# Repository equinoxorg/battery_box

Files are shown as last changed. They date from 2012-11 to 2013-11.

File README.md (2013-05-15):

#Battery Box 2013 Prototype

##Hardware
Hardware designs are made in eagle v6

##Software
Software is MPLAB IDE X v1.30 with the Hi Tech C Lite compiler

##Changes from 2012
Added Current Sense to prevent overcurrent failure
* Changed Microcontroller to add no volatile memory
  * Can be used to prevent over discharge and better batt level estimation
  * Can be used as very simple datalogger, data can be exported through Serial Data out pins
* Connectors have been added to board to reduce assembely time
* Surface mount components used to reduce manufacture cost

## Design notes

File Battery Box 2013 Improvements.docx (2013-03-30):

# Battery Box 2013 Improvements

# Surface Mount

All components should be replaced with their surface mount equivalent. For the resistors and capacitors the size of the devices should be 0805 to make hand soldering of test boards possible.

Some components will not be able to be switched to surface mount be switching as many as possible will bring down production costs and they will be able to be machine soldered.

# USB Changes

Firstly the USB power should have current limiting on. This will prevent damage to phones which try to pull more than 500mA. It will also stop the audible ringing when this situation occurs. To implement this we can use a device such as this (http://onecall.farnell.com/diodes-inc/ap1212lsg-13/ic-switch-usb-low-8sop/dp/1825303).

Secondly a voltage bias should be added to the USB data lines, this will make our charging ports compatible with more devices. The following website have looked into the correct biasing in detail and found these values to be the most compatible.

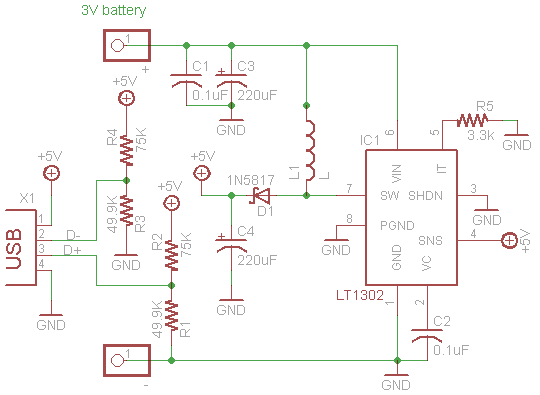
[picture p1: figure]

Figure 1- http://www.ladyada.net/make/mintyboost/parts.html

# Connector Mountings

Rather than connecting the mounting through terminal blocks and wires we should be mounting them straight onto the PCB and mounting the PCB directly behind the faceplate. For this we will carry on using the vertical mount USB sockets (here (http://onecall.farnell.com/lumberg/2410-01/usb-type-a-receptacle-panel/dp/1177882?Ntt=117-7882)) but will have to switch from panel mount to vertical PCB mount DC jacks. These jacks look suitable (http://uk.mouser.com/ProductDetail/Kycon/KLDVX-0202-B/?qs=sGAEpiMZZMvEZpvz4iUm3q0Yvn/b8os7).

We will also need to investigate how to mount the PCBs securely to the faceplate. The only connect made off the PCB will be to the power switch and battery. However if we could also mount the power switch on the PCB also then this would be beneficial but this seems very difficult. The battery and switch should be connected using something like this (http://onecall.farnell.com/molex/26-03-4020/housing-3-96mm-2way/dp/1756831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) which should be easier, more reliable and cheaper than the terminal blocks.

# Protection Circuit

Currently we have a PTC and fuse. These do not protect the Mosfet during over-current (output shorted to ground) situations as they do not act fast enough. Many boxes are failing due to this. We need to add faster acting input protection, possible a current sense resistor with the voltage drop connected to the analogue comparator of the PIC, this can be linked to an interrupt to disable the output and indicate the user of the error. This may still not be fast enough, so could also add a more resilient Mosfet.

Reverse battery protection could also be added if this is found to cause damage to the electrosnic.

# Charging Indication

We should provide some visual indication id charging. This can simply be done by flashing the bi-colour LED during charging.

# Optional Data-logging Unit

We would like a way to optional add data-logging systems to these boxes. This would profile how they are being used over time. We would not add these to all boxes due to cost but it would be nice to have the option to add this to some boxes. We could either design all PCBs to be able to do this but only solder the required data-logging components to selected boxes or add in a second data-logging PCB which monitors usage. We would have to think carefully about how we would retrieve the data from these boxes.

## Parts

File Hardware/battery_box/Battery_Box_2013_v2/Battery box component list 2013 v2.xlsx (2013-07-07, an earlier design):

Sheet: Component Sheet
 |  | Battery Box component list 2013
Board label | Quantity | Function | Manufacturer | Order code | Quantity | Price | Total Cost | Comments | Current quantity
 | 2 | Crimp terminal for plug | MOLEX | 2063715 | 2 | £0.14 | £0.28
 | 1 | Receptacle connector | MOLEX | 151866 | 1 | £0.17 | £0.17
 | 1 | Battery Crimp red | Multicomp | 9971882 | 1 | £0.16 | £0.16 | could get cheaper 1339227, but test quality first
 | 1 | Battery Crimp blue | MULTICOMP | 9971904 | 1 | £0.14 | £0.14 | Could get cheaper 488331, but test quality first
 | 1 | LED Housing | KINGBRIGHT | 1105124 | 1 | £0.10 | £0.10
 |  | Cable
 |  | PCB
 |  | USBS |  | 1696536 | 1 | £0.26 | £0.26 |  | 200
 |  | Programmer header | TE CONNECTIVITY / AMP | 1248143 |  |  |  | NOT ACTUALLY NEEDED TE CONNECTIVITY / AMP - 826926-5 - HEADER, STRAIGHT, 5WAY | 180
 | 1 | LED |  | 2001770 | 1 | £0.14 | £0.14 |  | 200
 | 2 | DC Socket |  |  | 2 | £0.22 | £0.44 | price for 500+ | 200
 | 1 | Battery connector header | MOLEX | 1012166 | 1 | £0.41 | £0.41 |  | 200
SW_POW | 1 | Switch | TE CONNECTIVITY | 758-1979 | 1 | £0.08 | £0.08 |  | 200
 | 1 | Switch Cap | MULTICOMP | 9561552 | 1 | £0.03 | £0.03 | MULTICOMP - KTSC-22K - CAP, ROUND, BLACK | 200
PTC | 1 | PTC | TE CONNECTIVITY | 1345935 | 1 | £0.19 | £0.19 |  | 3
IC4 | 1 | 5V regulator | NXP | 2057286 | 1 | £0.02 | £0.02 |  | 200
IC3 | 1 | PIC microcontroller | MICROCHIP | 1814945 | 1 | £1.01 | £1.01 | 70p in bulk | 192
R9, R16, R17 | 3 | 20k resistor | MULTICOMP | 2074395 | 3 | £0.01 | £0.03 |  | 92
R10, R19 | 2 | 10k resistor | MULTICOMP | 2074334 | 2 | £0.01 | £0.02
R12, R13 | 2 | 100k Resistor | MULTICOMP | 2073608 | 2 | £0.01 | £0.02 |  | 95
R1, R3 | 2 | 75k Resistor | MULTICOMP | 2073840 | 2 | £0.01 | £0.02 |  | 95
R14, R15 | 2 | 66k5 Resistor | VISHAY | 2139016 | 2 | £0.01 | £0.01 |  | 45
R2, R4 | 2 | 49.9k Resistor | PANASONIC | 2057651 | 2 | £0.02 | £0.03 |  | 45
R5, R6, R7 | 3 | 1k Resistor | MULTICOMP | 2073611 | 3 | £0.01 | £0.02 |  | 85
R18 | 1 | 1M Resistor | MULTICOMP | 2073615 | 1 | £0.01 | £0.01 |  | 98
R11 | 1 | 0.1 ohm resistor | BOURNS | 1865265 | 1 | £0.12 | £0.18 |  | 209
C1 | 1 | 1u capacitor | MULTICOMP | CA06731 | 1 | £0.01 | £0.01 |  | 99
C4 | 1 | 22u capacitor, 6.3v | MULTICOMP | CA06719 | 1 | £0.08 | £0.08 |  | 90
C2 | 1 | 22u capacitor, 16V | MULTICOMP | CA06789 | 1 | £0.23 | £0.23 |  | 200
C3 | 1 | 220u capacitor, 6.3V | PANASONIC | 9694340 | 1 | £0.35 | £0.35
IC2 | 1 | 12-5V Regulator | TEXAS INSTRUMENTS | SC10367 | 1 | £0.63 | £0.63 |  | 193
L1 | 1 | Inductor | MULTICOMP | 1864293 | 1 | £0.28 | £0.28 |  | 193
Q1 | 1 | P-MOS Power MOSFET | International Rectifier | 8649839 | 1 | £0.32 | £0.32 |  | 203
Q2 | 1 | N-MOS Signal MOSFET | NXP | 2191748 | 1 | £0.03 | £0.03 |  | 202
IC1 | 1 | Operational Amplifier | TEXAS INSTRUMENTS | 1755223 | 1 | £0.25 | £0.25 |  | 203
C5 | 1 | 10u Capacitor | MULTICOMP | 1759470 | 1 | 0.26 | 0.26 |  |  | 5
D2, D3 | 2 | Schottky Diode 40V output | MULTICOMP | 1861427 | 2 | 0.121 | 0.242 | Could be cheaper? | 400 | 5
D1 | 1 | Schottky Diode 20V output | MULTICOMP | 1861424 | 1 | 0.05 | 0.05 |  | 200 | 5
C6 | 1 | 0.1u Capacitor | AVX | 1327657 | 1 | 0.033 | 0.033 | Could get cheaper in smaller package, but didn’t have time to redesign board |  | 5
C8 | 1 | 10u Capacitor | TDK | 2309029 | 1 | 0.028 | 0.028 |  |  | 5
 |  |  |  |  |  |  | £6.55

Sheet: Ordering Sheet
 | Supplier Ref | Quantity | Description | Our Description
 | 1248143 | 200 | TE CONNECTIVITY / AMP - 826926-5 - HEADER, STRAIGHT, 5WAY | programmer thing!!! (headers)
 | 2073608 | 400 | MULTICOMP - MCMR08X1003FTL - RESISTOR, CERAMIC, 100K, 0.125W, 1% | 100k Resistor | x
 | 1012166 | 200 | MOLEX - 39-29-1028 - HEADER, RIGHT ANGLE, MINI-FIT, 2WAY | Battery connector header
Check this | 1555983 | 200 | TE CONNECTIVITY / ALCOSWITCH - FSM6JH - SWITCH, SPST, 0.05A, 24VDC, THT | Switch
 | 1345935 | 200 | TE CONNECTIVITY / RAYCHEM - MINISMDC260F - POLYSWITCH, SMD, 1812, 2.6A | PTC
 | 2057286 | 200 | NXP - NX1117CE50Z - LDO, 5.0V, 1.25%, SOT223 | 5V regulator
 | 1814945 | 200 | MICROCHIP - PIC16F1824-I/SL - MCU, 8BIT, 7K FLASH, 12 I/O, 14SOIC | PIC microcontroller
 | 2074395 | 600 | MULTICOMP - MCSR08X2002FTL - RESISTOR, 0805, 20K, 1%, ANTI SULFUR | 20k resistor | x
 | 2074334 | 400 | MULTICOMP - MCSR08X1002FTL - RESISTOR, CERAMIC, 10K, 0.125W, 1% | 10k resistor | x
 | 2073840 | 400 | MULTICOMP - MCMR08X7502FTL - RESISTOR, 0805, 75K, 1%, ANTI SULFUR | 75k Resistor | x
 | 2139016 | 400 | VISHAY DRALORIC - CRCW080566K5FKEA - RESISTOR, 0805, 66K5, 1% | 66k5 Resistor
 | 2057651 | 400 | PANASONIC - ERJ6ENF4992V - RESISTOR, 0805, 49K9 1%, 0.125W | 49.9k Resistor
 | 2073611 | 600 | MULTICOMP - MCMR08X102 JTL - RESISTOR, ANTI SULFUR, 1K, 0805, 5% | 1k Resistor | X
 | 2073615 | 200 | MULTICOMP - MCMR08X105 JTL - RESISTOR, ANTI SULFUR, 1M, 0805, 5% | 1M Resistor | X
 | 1865265 | 200 | BOURNS - CRM2512-FX-R100ELF - RESISTOR, 0.100R, 2W, 1% | 0.1 ohm resistor
 | CA06731 | 200 | MULTICOMP - MCCA000543 - MLCC, 0805, Y5V, 16V, 1UF | 1u capacitor
Check this | CA06719 | 200 | MULTICOMP - MCCA000536 - MLCC, 0805, X5R, 6.3V, 22UF | 22u capacitor, 6.3v
Check this | CA06789 | 200 | MULTICOMP - MCCA000583 - MLCC, 1210, X5R, 16V, 22UF | 22u capacitor, 16V
 | 9694340 | 200 | PANASONIC - EEEFC0J221P - CAP ALUM ELEC, 220UF, 6.3V, 20%, SMD | 220u capacitor, 6.3V
 | SC10367 | 200 | TEXAS INSTRUMENTS - LM2574M-5.0 - SWITCHING REG 0.5A 5.0V, SMD, 2574 | 12-5V Regulator
 | 1864293 | 200 | MULTICOMP - MCBFS7330-331MU - INDUCTOR, 330UH, 20%, 1.15A | Inductor
 | 8649839 | 200 | INTERNATIONAL RECTIFIER - IRFR5505PBF - MOSFET, P, -55V, -18A, D-PAK | P-MOS Power MOSFET
 | 2191748 | 200 | NXP - NX7002AKW - MOSFET, SINGLE, N-CH, 60V, 0.17A, SOT323 | N-MOS Signal MOSFET
 | 1755223 | 200 | TEXAS INSTRUMENTS - TL103WID - IC, OP-AMP GP 900KHZ DUAL 8SOIC | Operational Amplifier
 | 1759470 | 200 | MULTICOMP - MCCA000586 - MLCC, 1210, X5R, 25V, 10UF | 10u Capacitor
 | 1861427 | 400 | MULTICOMP - SS54 - DIODE, SCHOTTK, RECTIF, 5A, 40V, SMC | Schottky Diode 40V output
 | 1861424 | 200 | MULTICOMP - SS12B - DIODE, SCHOTTK, RECTIF, 1A, 20V, SMB | Schottky Diode 20V output
 | 1327657 | 200 | AVX - 04026D104KAT2A - CAP MLCC, 0.1UF, 6.3V, X5R, 10%, 0402 | 0.1u Capacitor | x
 | 2309029 | 200 | TDK - C2012X5R0J106M/1.25 - CAPACITOR , 10UF, 6.3V, X5R, 20%, 0805 | 10u Capacitor

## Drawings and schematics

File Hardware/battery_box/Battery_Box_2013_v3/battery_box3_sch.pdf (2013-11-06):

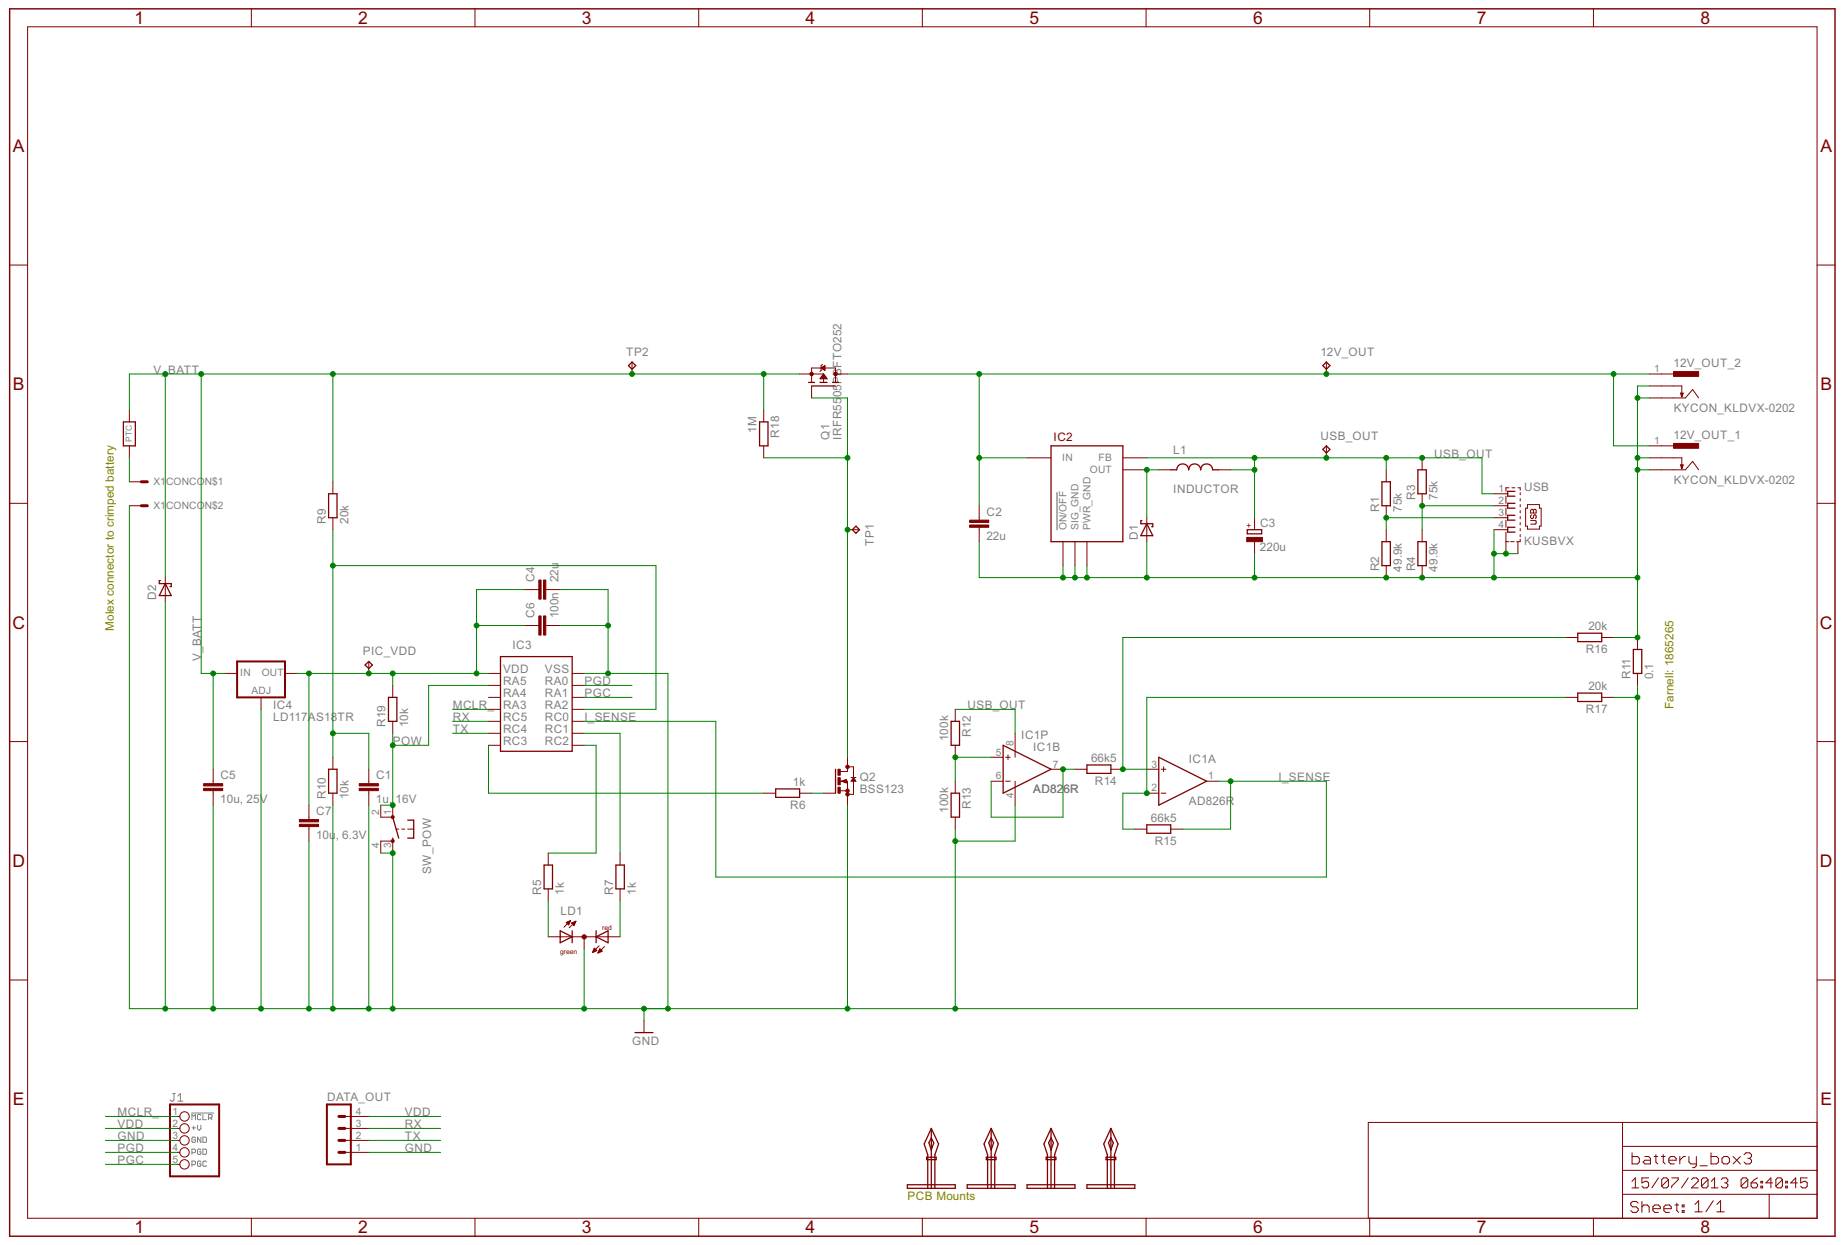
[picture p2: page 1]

Molex connector to crimped battery

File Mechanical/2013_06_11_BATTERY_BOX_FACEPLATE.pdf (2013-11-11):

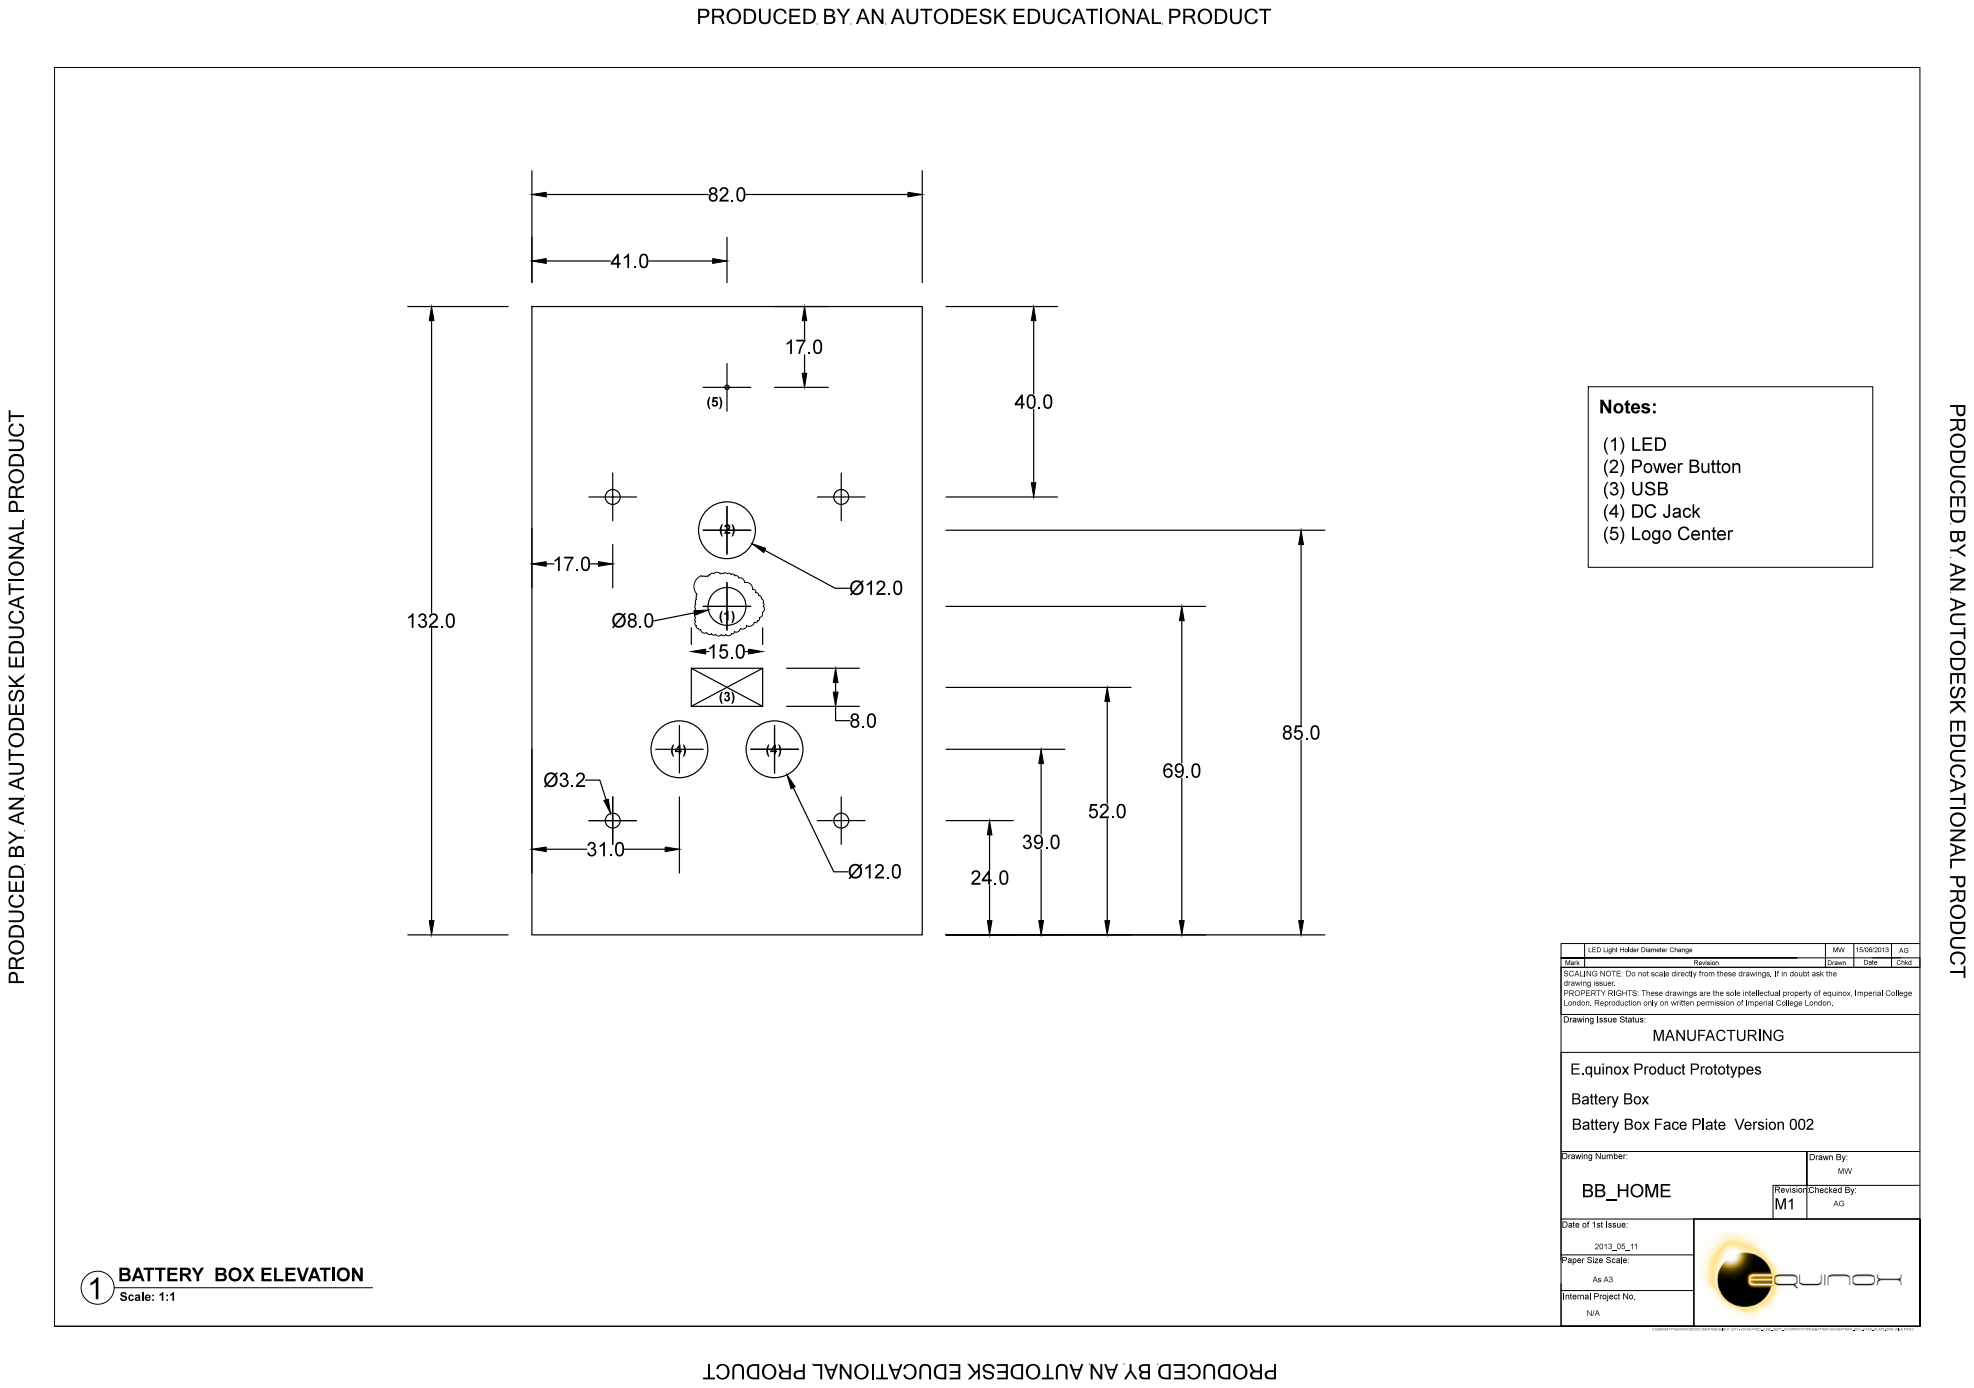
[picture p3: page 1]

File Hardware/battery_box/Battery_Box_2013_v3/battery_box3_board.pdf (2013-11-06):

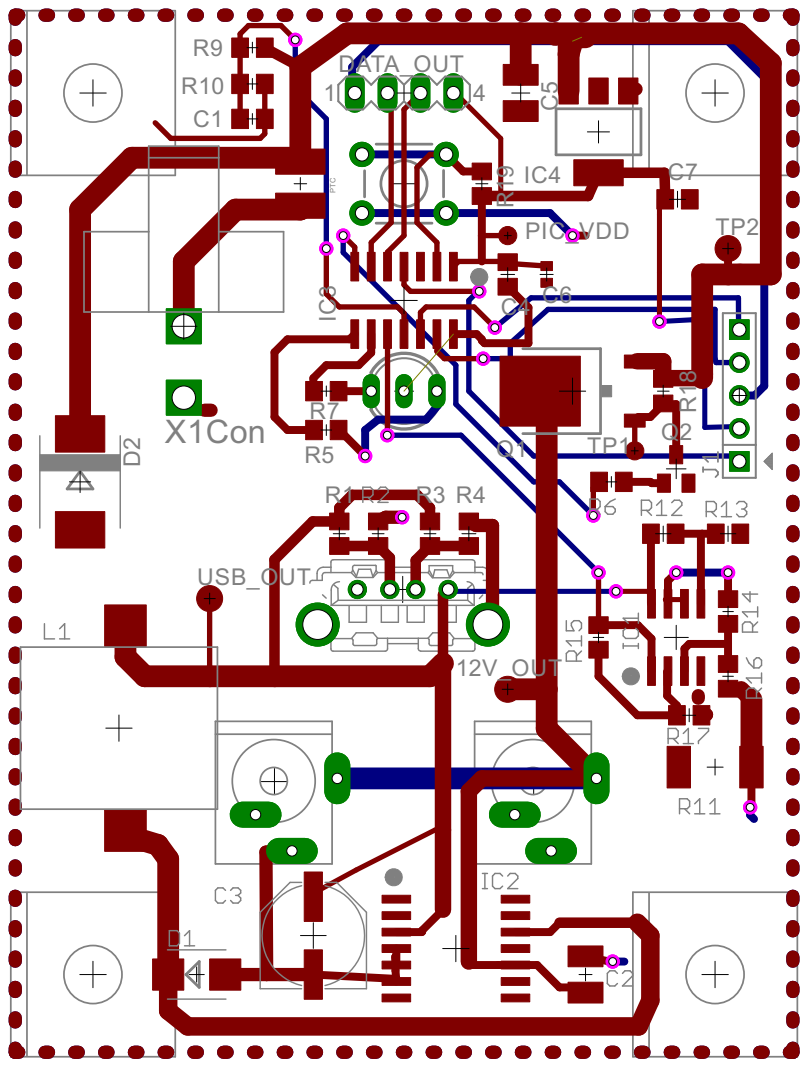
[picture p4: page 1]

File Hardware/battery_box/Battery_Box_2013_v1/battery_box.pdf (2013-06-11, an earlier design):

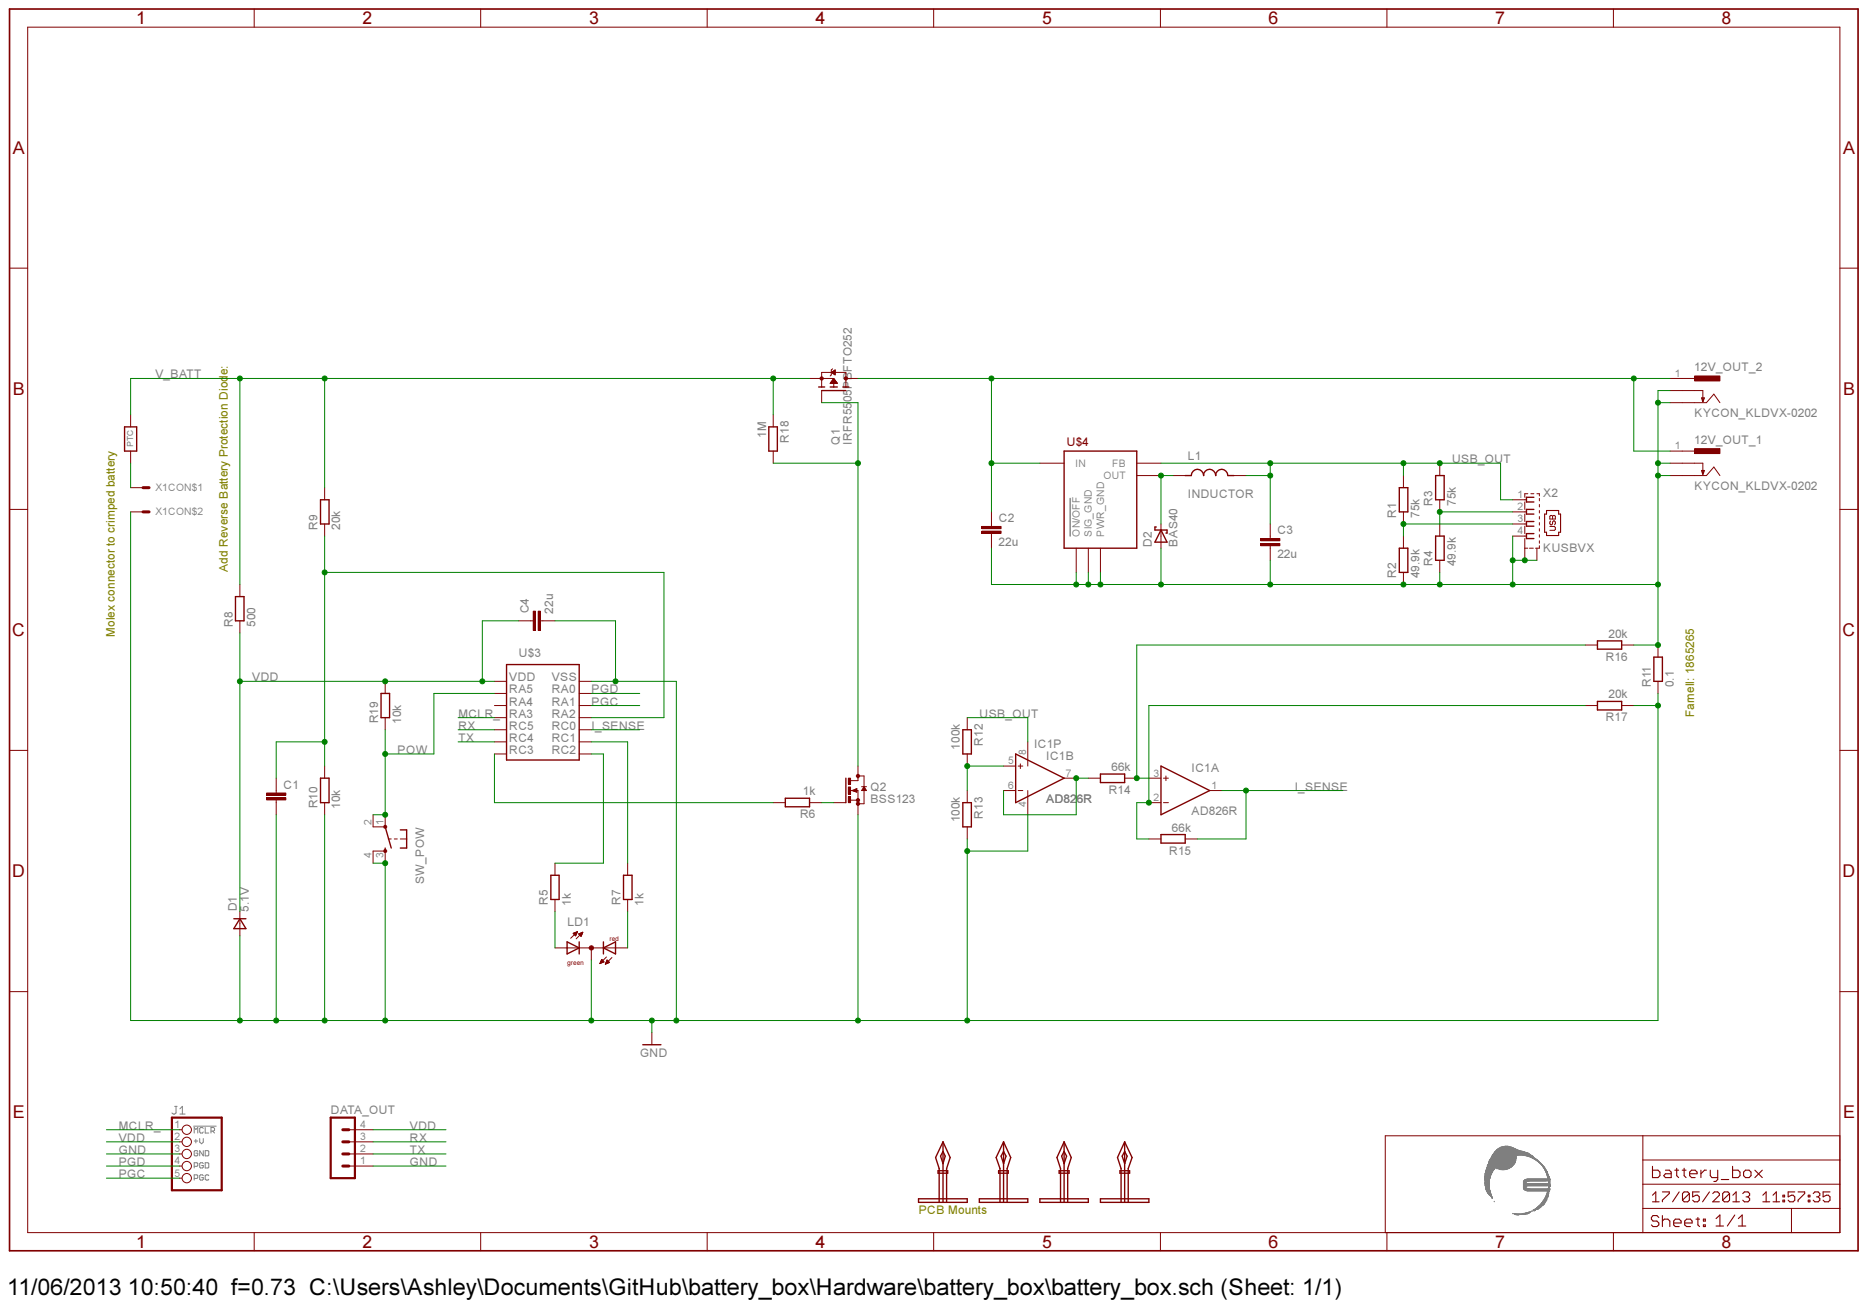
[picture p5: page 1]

Add Reverse Battery Protection Diode:

Molex connector to crimped battery

11/06/2013 10:50:40 f=0.73 C:\Users\Ashley\Documents\GitHub\battery_box\Hardware\battery_box\battery_box.sch (Sheet: 1/1)

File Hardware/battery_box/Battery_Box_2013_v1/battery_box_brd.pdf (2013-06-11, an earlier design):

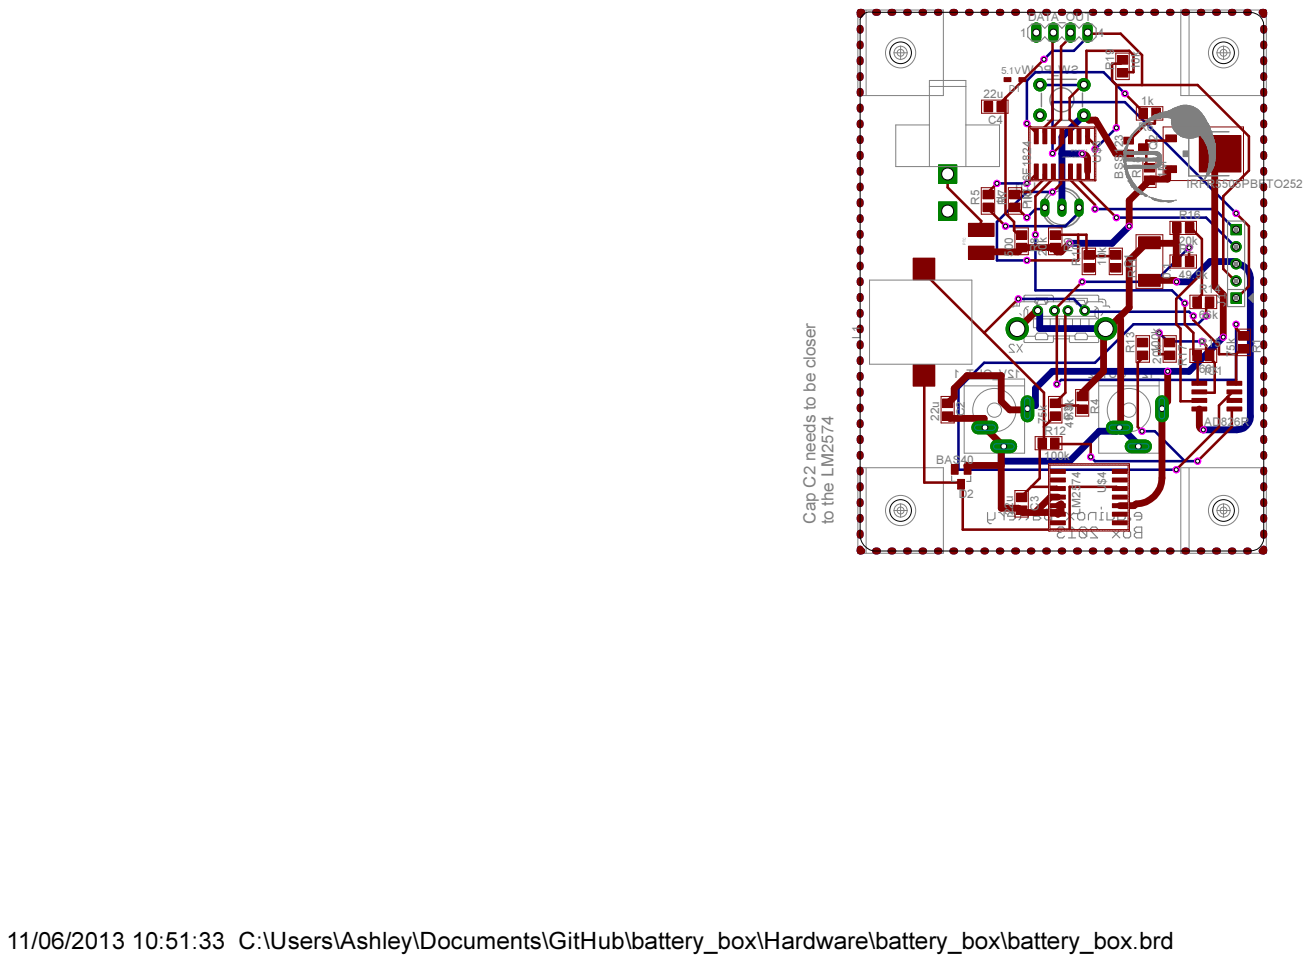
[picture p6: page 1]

Cap C2 needs to be closer

11/06/2013 10:51:33 C:\Users\Ashley\Documents\GitHub\battery_box\Hardware\battery_box\battery_box.brd

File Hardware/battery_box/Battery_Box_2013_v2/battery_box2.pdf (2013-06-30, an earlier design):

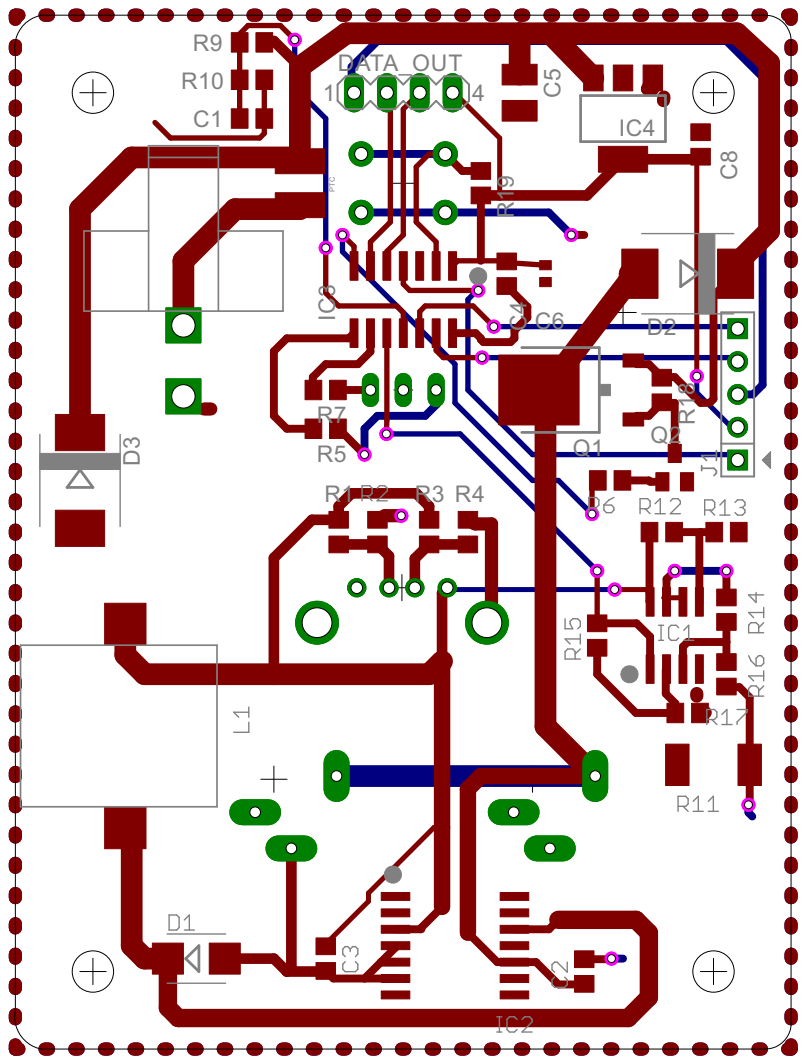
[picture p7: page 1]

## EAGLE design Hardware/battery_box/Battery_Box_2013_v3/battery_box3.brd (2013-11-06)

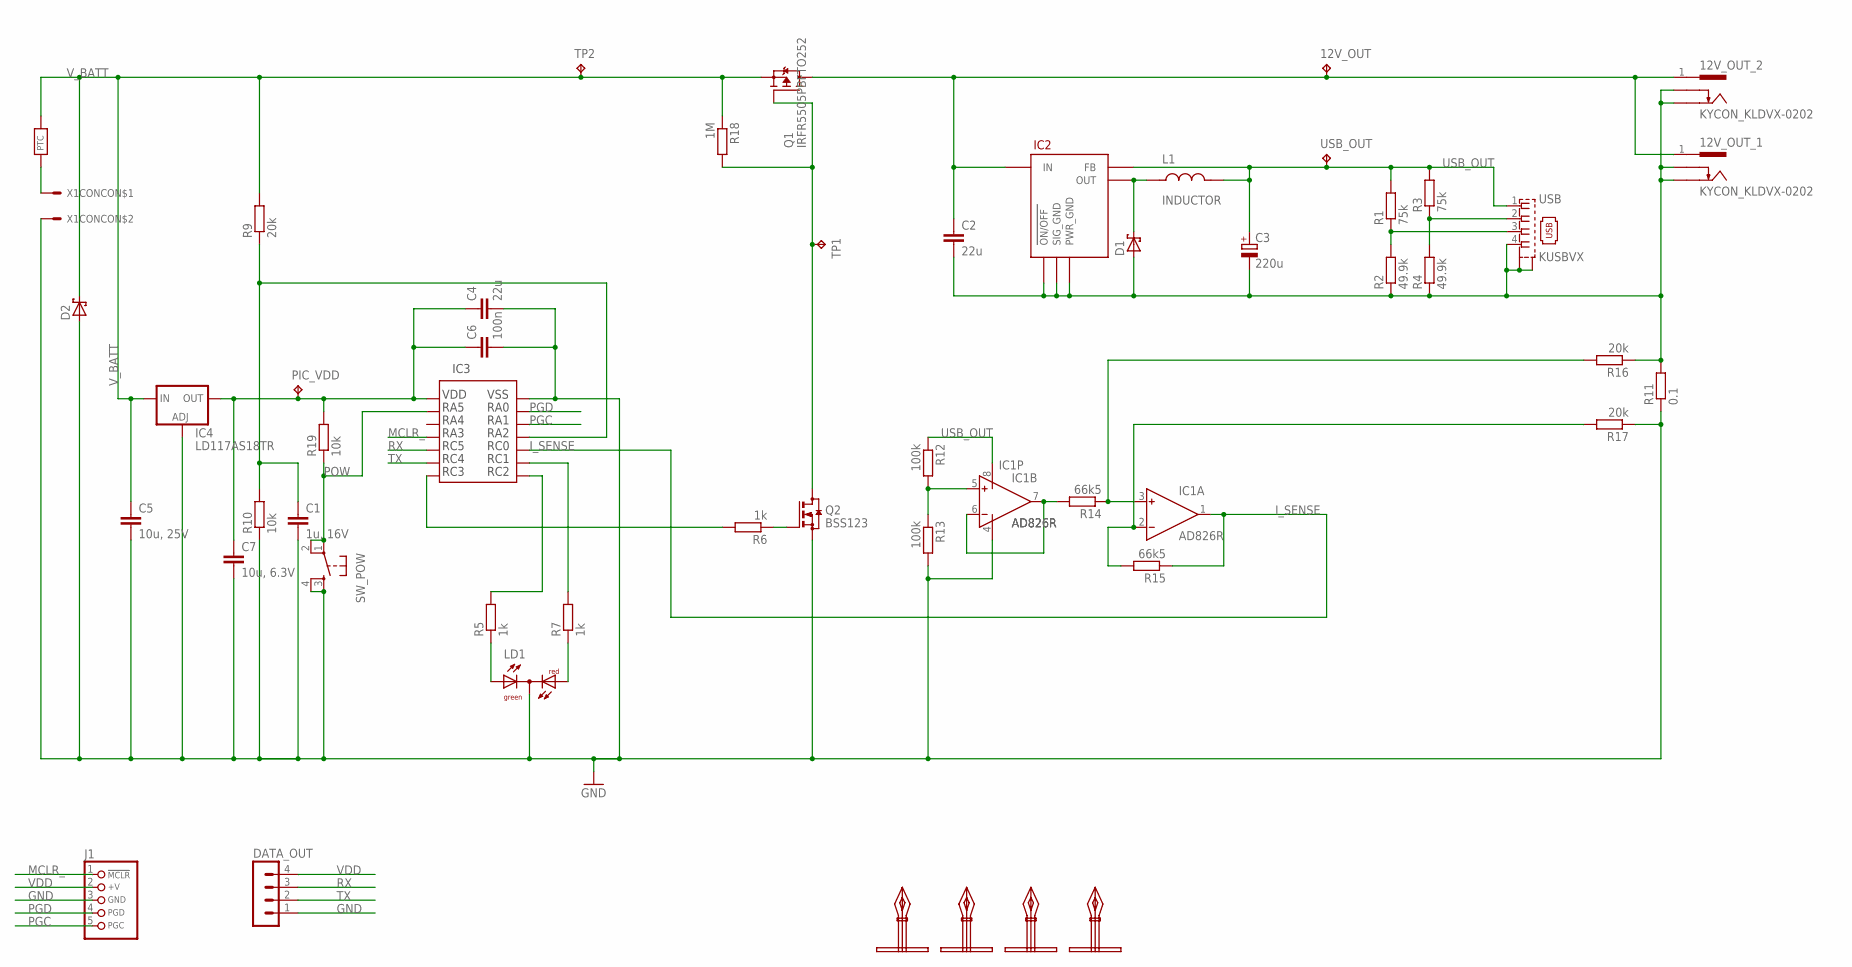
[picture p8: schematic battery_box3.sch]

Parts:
12V_OUT: TPTP20R; TP20R
12V_OUT_1, 12V_OUT_2: KYCON_KLDVX-0202; KYCON_KLVDX_2020_B
C1: 1u, 16V; C0805
C2: 22u; C1210
C3: 220u; PANASONIC_E
C4: 22u; C0805
C5: 10u, 25V; C1210
C6: 100n; C0402
C7: 10u, 6.3V; C0805
D1: SCHOTTKY-DIODESMD; SMB
D2: SCHOTTKY-DIODESMC; SMC
DATA_OUT: MA04-1
IC1: AD826R; SO8
IC2: LM2574; SO14W
IC3: PIC16F1824; SO-14
IC4: LD117AS18TR; SOT223
J1: CON_HEADER_PRG_PIC_ICSPA; HEADER_PRG_1X05
L1: INDUCTOR; SMD_INDUCTOR
LD1: DUOLED-RG-C; DUOLED-C-5MM
PIC_VDD: TPTP14R; TP14R
Q1: IRFR5505PBFTO252; TO252
Q2: BSS123; SOT23
R1, R3: 75k; R0805
R2, R4: 49.9k; R0805
R5, R6, R7: 1k; R0805
R9, R16, R17: 20k; R0805
R10, R19: 10k; R0805
R11: 0.1; R2512
R12, R13: 100k; R0805
R14, R15: 66k5; R0805
R18: 1M; R0805
SW_POW: TAC_SWITCHPTH; TACTILE-PTH
TP1: TPTP14R; TP14R
TP2: TPTP20R; TP20R
U$2: PTC; MINISMDC260F
U$5, U$6, U$7, U$8: PCB_MOUNT_RICHO; PCBMOUNT
USB: KUSBVX
USB_OUT: TPTP20R; TP20R
X1CON: CON_MOLEX_39_29_1028; MOLEX_39_29_1028

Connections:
12V_OUT: 12V_OUT.TP, 12V_OUT_1.1, 12V_OUT_2.1, C2.1, IC2.10 (IN), Q1.3 (D)
GND: C1.2, C4.2, C5.2, C6.2, C7.2, D2.A, DATA_OUT.1, IC1.4 (V-), IC3.14, IC4.1 (ADJ), J1.3 (GND), LD1.C, Q2.2 (S), R10.1, R11.1, R13.2, R17.1, SW_POW.3, SW_POW.4, X1CON.P$2
GND_OUTPUT: 12V_OUT_1.2, 12V_OUT_1.3, 12V_OUT_2.2, 12V_OUT_2.3, C2.2, C3.-, D1.A, IC2.4 (SIG_GND), IC2.5 (ON/OFF), IC2.6 (PWR_GND), R2.1, R4.1, R11.2, R16.1, USB.4, USB.M1 (S1), USB.M2 (S2)
I_SENSE: IC1.1 (OUT), IC3.10, R15.1
MCLR_: IC3.4, J1.1 (/MCLR)
unnamed: LD1.AR, R7.1
unnamed: R1.1, R2.2, USB.3
unnamed: LD1.AX (AG), R5.1
unnamed: R3.1, R4.2, USB.2
unnamed: U$2.P$1, X1CON.P$1
unnamed: IC3.9, R7.2
unnamed: C1.1, IC3.11, R9.1, R10.2
unnamed: D1.C, IC2.12 (OUT), L1.P$1
unnamed: IC3.8, R5.2
unnamed: Q1.1 (G), Q2.3 (D), R18.2, TP1.TP
unnamed: Q2.1 (G), R6.1
unnamed: IC3.7, R6.2
unnamed: IC1.3 (IN+), R14.1, R16.2
unnamed: IC1.2 (IN-), R15.2, R17.2
unnamed: IC1.5 (IN+), R12.2, R13.1
unnamed: IC1.6 (IN-), IC1.7 (OUT), R14.2
PGC: IC3.12, J1.5 (PGC)
PGD: IC3.13, J1.4 (PGD)
POW: IC3.2, R19.1, SW_POW.1, SW_POW.2
RX: DATA_OUT.3, IC3.5
TX: DATA_OUT.2, IC3.6
USB_OUT: C3.+, IC1.8 (V+), IC2.3 (FB), L1.P$2, R1.2, R3.2, R12.1, USB.1, USB_OUT.TP
VDD: C4.1, C6.1, C7.1, DATA_OUT.4, IC3.1, IC4.4 (OUT), J1.2 (+V), PIC_VDD.TP, R19.2
V_BATT: C5.1, D2.C, IC4.3 (IN), Q1.2 (S), R9.2, R18.1, TP2.TP, U$2.P$2

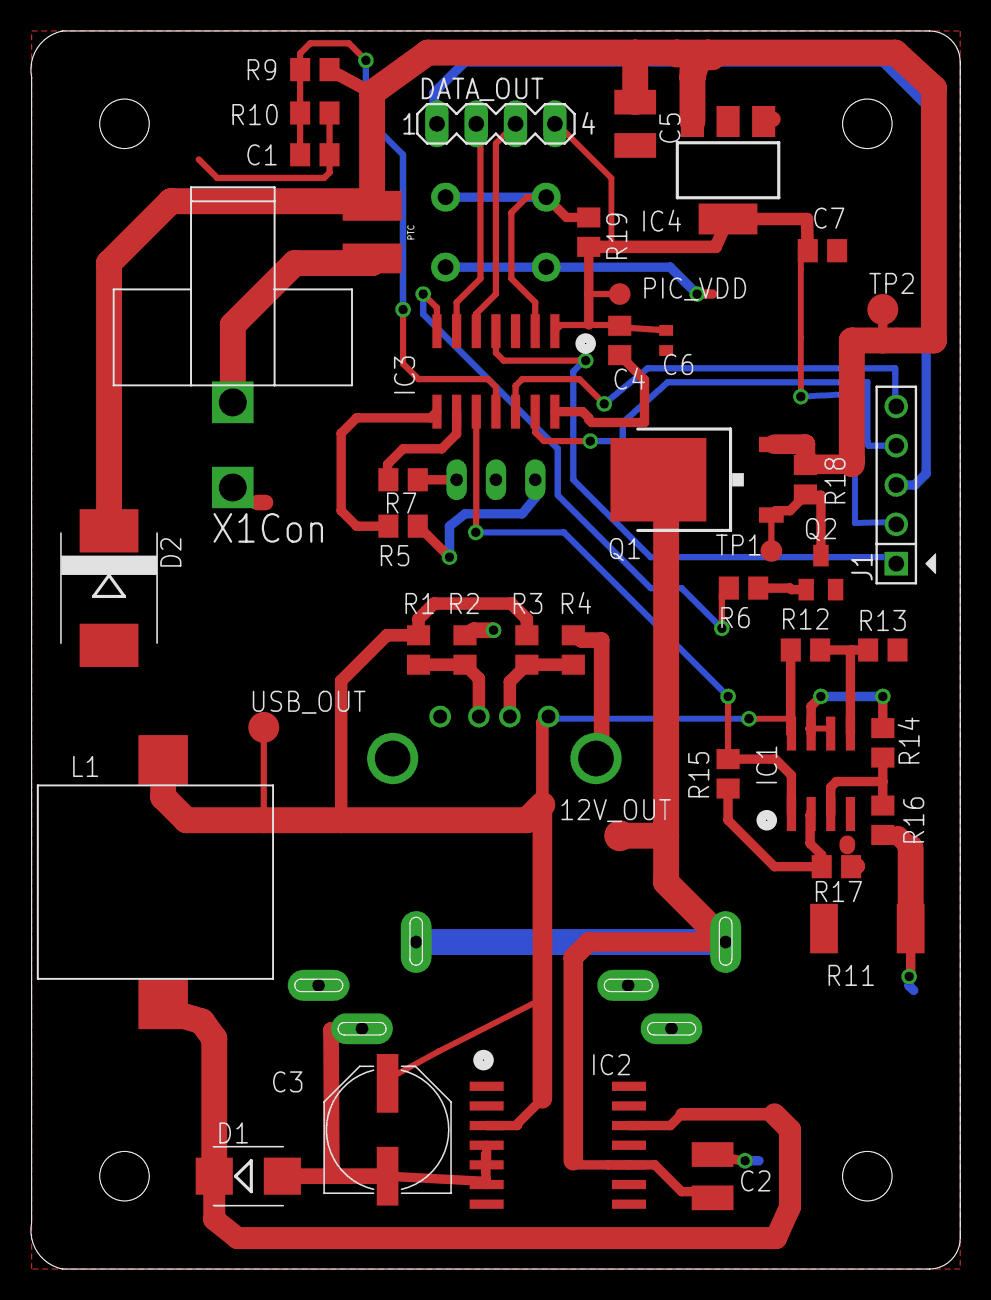
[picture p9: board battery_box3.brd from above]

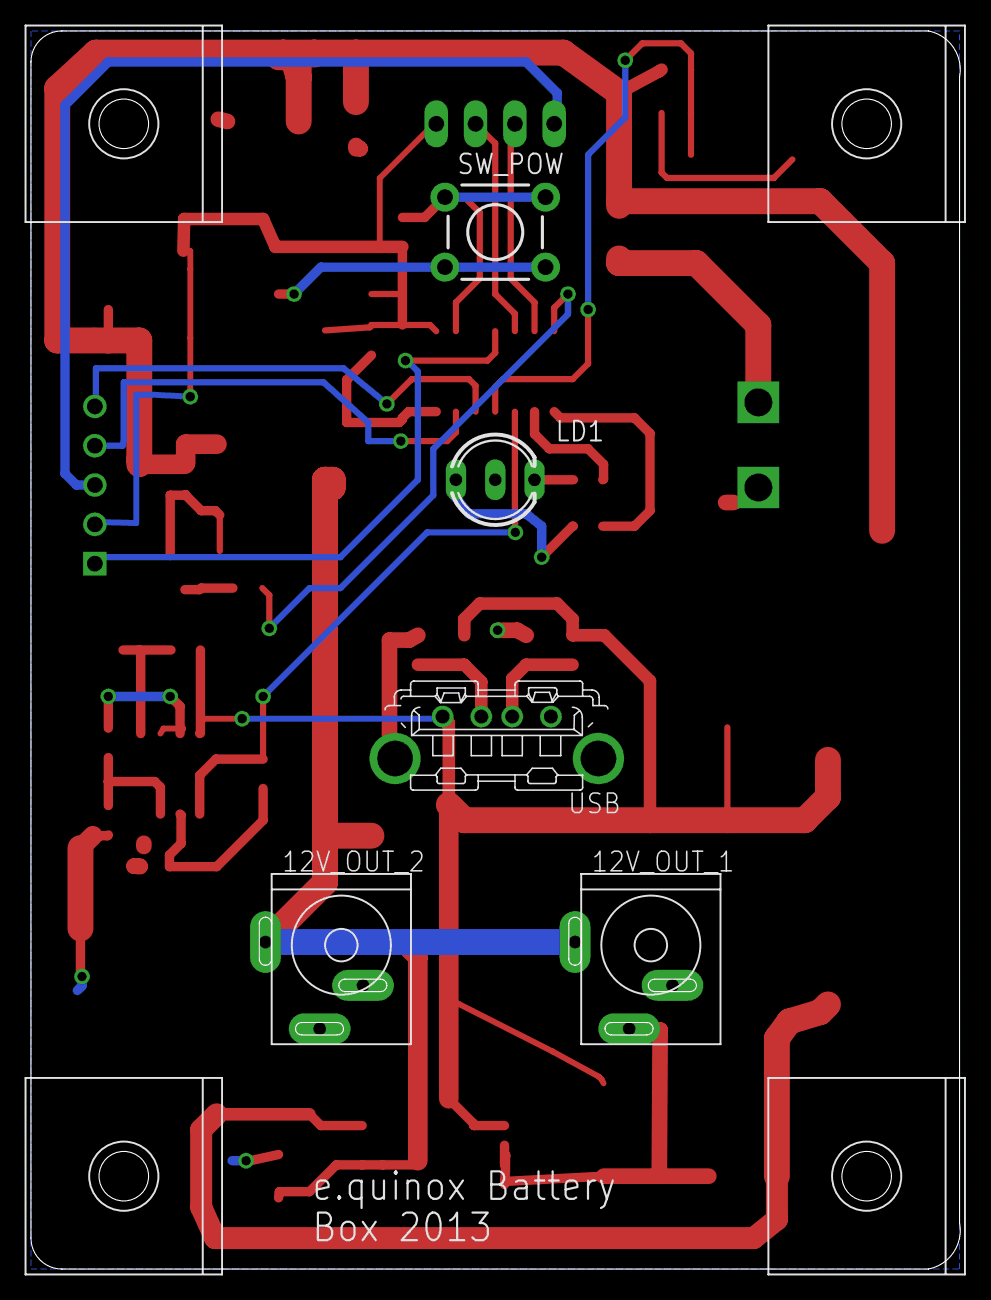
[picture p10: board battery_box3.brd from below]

Board: 2 copper layers, 60.0 x 80.0 mm, 52 parts (9 on the bottom side), 29 nets.

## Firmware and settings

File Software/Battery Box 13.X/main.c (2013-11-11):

/*--------------------------- Low Voltage Cut Off ------------------------------
 |  E.quinox battery box low voltage cutout circuit
 |  Copyright (C) 2013  Ashley Grealish & Yuchen Wang - www.e.quinox.org
 |
 |  This program is free software: you can redistribute it and/or modify
 |  it under the terms of the GNU General Public License as published by
 |  the Free Software Foundation, either version 3 of the License, or
 |  (at your option) any later version.
 |
 |  This program is distributed in the hope that it will be useful,
 |  but WITHOUT ANY WARRANTY; without even the implied warranty of
 |  MERCHANTABILITY or FITNESS FOR A PARTICULAR PURPOSE.  See the
 |  GNU General Public License for more details.
 |
 |  You should have received a copy of the GNU General Public License
 |  along with this program.  If not, see <http://www.gnu.org/licenses/>.
 |
 |
 |  IDE : MPLAB X IDE v1.60
 |  Compiler: hi-tech-picc v9.83 - lite version
 |
 |                   __________
 |      VCC         |1      14| GND
 |(RA5) POW_SW      |2      13| PGD     (Programming Pin)
 |                  |3      12| PGC     (Programming Pin)
 |      ~MCLR       |4      11| BATT_V (Stepdown to 0-5V)   (RA2/AN2)
 |(RC5)	RX          |5      10| I_SENSE                     (RC0/AN4)
 |(RC4)	TX          |6       9| RED LED     RC1
 |(RC3) LVCO        |7       8| GREEN LED   RC2
 |                  -----------
 | 	I_SENSE is the charging current
 |	BATT_V is the battery voltage, steoped down to 1/3 of its normal value
 |      RX and TX are for outputting data (currently unimplemented)
 |      POW is for putting the chip to sleep
 *----------------------------------------------------------------------------*/

/*----------------------------------------TODO----------------------------------
 * Add low pass filtering to ADC readings
 * Fix flashing on over-load if possible
 -----------------------------------------------------------------------------*/

#include <htc.h> //Hi Tech compiler libraries
#include <stdint.h>



// PIC16F1824 Configuration Bit Settings - Int Osc at 4Mhz, Watchdog off
__CONFIG(FOSC_INTOSC & WDTE_OFF & PWRTE_OFF & MCLRE_ON & CP_OFF & CPD_OFF & BOREN_ON & CLKOUTEN_OFF & IESO_ON & FCMEN_ON);
__CONFIG(WRT_OFF & PLLEN_ON & STVREN_ON & BORV_LO & LVP_ON);

#ifndef _XTAL_FREQ
    // Unless already defined assume 4MHz system frequency
    #define _XTAL_FREQ 4000000
#endif

//Port C Output Ports
#define LVCO_PIN	(1 << 3)    //RC3
#define LEDR_PIN	(1 << 1)    //RC1
#define LEDG_PIN	(1 << 2)    //RC2
#define I_SENSE_PIN     (1 << 0)

//Analogue input pins
#define BATT_V          2
#define CURR_V          4
#define I_SENSE_INPUT   4       //or should this be 0?

#define FULL_BATT_VOLTAGE       14.0f
#define CHARGED_BATT_VOLTAGE    12.3f
#define CUTOFF_VOLTAGE          10.8f
#define VCC_VOLTAGE             5.0f
#define LOW_BATT_PERCENTAGE     0.25f
#define MIN_CHARGING_CURRENT    0.25f
#define OVER_CURRENT            0.8f


//Converts the above levels to ADC values - [DONT EDIT]
#define LOW_BATT_VOLTAGE            ( (FULL_BATT_VOLTAGE-CUTOFF_VOLTAGE)*LOW_BATT_PERCENTAGE + CUTOFF_VOLTAGE )
#define LOW_BATT_LEVEL              ( (uint16_t) ( (LOW_BATT_VOLTAGE/3.0f) / (( VCC_VOLTAGE /(float)0x3FF) ) ))
#define CUTOUT_LEVEL                ( (uint16_t) ( (CUTOFF_VOLTAGE/3.0f)/( VCC_VOLTAGE / (float)0x3FF) ) )
#define CHARGED_BATT_VOLTAGE_LEVEL  ( (uint16_t) ( (CHARGED_BATT_VOLTAGE/3.0f)/( VCC_VOLTAGE / (float)0x3FF) ) )
#define CHARGING_CURRENT_LEVEL      ( (uint16_t) ( ((VCC_VOLTAGE/2) - MIN_CHARGING_CURRENT)/( VCC_VOLTAGE / (float)0x3FF) ) )
#define OVER_CURRENT_LEVEL          ( (uint16_t) ( ((VCC_VOLTAGE/2) + OVER_CURRENT)/( VCC_VOLTAGE / (float)0x3FF) ) )
#define OVER_CHARGING_CURRENT_LEVEL ( (uint16_t) ( ((VCC_VOLTAGE/2) - OVER_CURRENT)/( VCC_VOLTAGE / (float)0x3FF) ) )


//State Machine States
#define STATE_ON    0
#define STATE_OFF   1
#define STATE_SLEEP 2

#define ADC_OVERSAMPLES 8

#define POLL_INTERVAL_MS 10

//Global Variable
char state;

//Function definitions
void init_hardware();
uint16_t read_ADC(char);
uint16_t read_ADC_average(unsigned char adc_channel);

void main(void)
{
    uint16_t adc_average;
    uint16_t adc_result;
    int i;
    uint16_t current;

    init_hardware();

    __delay_ms(500);

    if (eeprom_read(0xF001))
        state = STATE_OFF;
    else
        state = STATE_ON;

    while (1)
    {
        //Processes the ADC value and switches outputs accordingly
        switch (state)
        {
            case STATE_SLEEP:
                PORTC &= ~(LEDR_PIN | LEDG_PIN | LVCO_PIN);                     //turns off all O/P
                SLEEP();
                break;

            case STATE_OFF:

                adc_result = 0;
                adc_result = read_ADC_average(BATT_V);
                if (adc_result > CHARGED_BATT_VOLTAGE_LEVEL)
                {
                    eeprom_write(0xF001, 0);
                    state = STATE_ON;
                }
                else
                    state = STATE_SLEEP;
                break;


            case STATE_ON:
                //Turn on Green LED and O/P
                PORTC |= (LEDG_PIN | LVCO_PIN);
                __delay_ms(50);                                                 //allow voltage to stabilise
                //Read the ADC and oversamples to improve accuracy
                adc_average = 0;
                adc_result = read_ADC_average(BATT_V);
                if (adc_result < CUTOUT_LEVEL)
                {
                    //writes a 1 into EEPROM
                    eeprom_write(0xF001, 1);
                    //Turn off Green LED here and Turn on Red LED
                    PORTC &= ~LEDG_PIN;
                    PORTC |= LEDR_PIN;
                    //Turn off output
                    PORTC &= ~LVCO_PIN;
                    //Turn the state to OFF
                    state = STATE_OFF;
                }
                else if  (adc_result < LOW_BATT_LEVEL)                          //NOTE: LOW VOLTAGE FLICKER OCCURS IF THIS LOOP IS EXECUTED
                {
                    //Turn on Grean and Red Led for orange
                    PORTC |= (LEDG_PIN | LEDR_PIN | LVCO_PIN );
                }
                else
                {
                    //Averages the read ADC samples
                    adc_result = read_ADC_average(I_SENSE_INPUT);
                    if (adc_result > OVER_CURRENT_LEVEL || adc_result < OVER_CHARGING_CURRENT_LEVEL)
                    {
                        PORTC |= LEDR_PIN;
                        state = STATE_SLEEP;
                    }
                    else if (adc_result < CHARGING_CURRENT_LEVEL)
                    {
                        PORTC &= ~LEDG_PIN;
                        __delay_ms(100);
                    }
                }
                break;
        }
        //Waits a set time before reading the ADC again
        __delay_ms(POLL_INTERVAL_MS);
    }

}

void init_hardware(void)
{
    //setup all output ports by clearing bits
    TRISC &= ~(LVCO_PIN | LEDG_PIN | LEDR_PIN);

    //Turn on green LED
    PORTC |= (LEDG_PIN);
    //Turn off red LED
    PORTC &= ~(LEDR_PIN);
    //Turn off output pin
    PORTC &= ~(LVCO_PIN);

    //Set up adc
    ADCON1 = 0b10100000;

    //Enable the b_sense pin as analogue input
    ANSELA |= 1 << 3;
    ANSELC |= 1 << 1;

    //Set up the chip for interrupts
    IOCAP |= 1 << 5;                                                            //enable interrupt-on-change for RA5
    IOCAN = 0x0;
    INTCON = 0b10001000;                                                        //enable global interrupt (check if this bit is needed), and enable interrupt-on-change
    ei();                                                                       //enable global interrupts (test to see if this is needed
}

uint16_t read_ADC(unsigned char adc_channel)
{

    // Clear the adc Channel
    ADCON0 &= ~0b01111100;

    // Set up ADC with correct Channel
    ADCON0 |= (adc_channel & 0b00011111) << 2;

    //Enable the ADC
    ADCON0 |= 0x01;

    //Start the conversion
    ADCON0 |= 0x02;

    //Wait for conversion to finish
    while (ADCON0 & 0b00000010);

    //Turn off ADC to save power
    ADCON0 = 0b11000000;

    //Return the 10 bit results made into a 16 bit int
    return ( ((uint16_t)ADRESH) << 8) | ADRESL ;

}

uint16_t read_ADC_average(unsigned char adc_channel)
{
    uint16_t adc_average = 0;
    int i;
    for (i = 0; i < ADC_OVERSAMPLES; i++)
        adc_average += read_ADC(adc_channel);

   //Averages the read ADC samples
   return (adc_average / ADC_OVERSAMPLES);
}

void interrupt ISR (void)
{

    if (IOCAF & (1 << 5))
    {
        if (state != STATE_SLEEP)
        {
            PORTC &= ~(LEDR_PIN | LEDG_PIN | LVCO_PIN);
            PORTC |= LEDR_PIN;
            state = STATE_SLEEP;                                                //Sleep
        }
        else
        {
            PORTC &= ~(LEDR_PIN | LEDG_PIN | LVCO_PIN);
            if (eeprom_read(0xF001))                                            //Checks if STATE_OFF/LVDC has been triggered
            {
                PORTC |= (LEDR_PIN|LEDG_PIN);
                state = STATE_OFF;
            }
            else
            {
                PORTC |= LEDG_PIN;
                state = STATE_ON;
            }
        }
    }
    IOCAF = 0x0;
}

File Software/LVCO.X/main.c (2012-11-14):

/*--------------------------- Low Voltage Cut Off ------------------------------
 | 	E.quinox battery box low voltage cutout circuit
 |  Copyright (C) 2011  Ashley Grealish - e.quinox.org
 |
 |  This program is free software: you can redistribute it and/or modify
 |  it under the terms of the GNU General Public License as published by
 |  the Free Software Foundation, either version 3 of the License, or
 |  (at your option) any later version.
 |
 |  This program is distributed in the hope that it will be useful,
 |  but WITHOUT ANY WARRANTY; without even the implied warranty of
 |  MERCHANTABILITY or FITNESS FOR A PARTICULAR PURPOSE.  See the
 |  GNU General Public License for more details.
 |
 |  You should have received a copy of the GNU General Public License
 |  along with this program.  If not, see <http://www.gnu.org/licenses/>.    
 |
 |
 |  IDE : MPLAB X IDE v1.20
 |  Compiler: hi-tech-picc v9.83 - lite version
 |
 |                   __________
 |	VCC         |1      14| GND
 |                  |2      13|
 |                  |3      12|
 |                  |4      11| B_SENSE (Stepdown to 0-5V)
 |	LED_R       |5      10|
 |	LED_G       |6       9|
 |	LV CUTOFF   |7       8|
 |                  -----------
 | 	LV_CUTOFF controls the MOSFET which turns off the output power
 |	B_SENSE is the battery voltage, steoped down to 1/3 of its normal value 
 |
 *----------------------------------------------------------------------------*/

/*----------------------------------------TODO----------------------------------
 * Add low pass filtering to ADC readings
 * Fix flashing on over-load if possible
 -----------------------------------------------------------------------------*/

#include <htc.h> //Hi Tech compiler libraries
#include <stdint.h>


// PIC16F526 Configuration Bit Settings - Int Osc at 4Mhz, Watchdog off
__CONFIG(FOSC_INTRC_RB4 & WDTE_OFF & CP_OFF & MCLRE_ON & IOSCFS_4MHz & CPDF_OFF);

#ifndef _XTAL_FREQ
    // Unless already defined assume 4MHz system frequency
    #define _XTAL_FREQ 4000000
#endif

//Port C Output Ports
#define LEDG_PIN	(1 << 4)
#define LEDR_PIN	(1 << 5)
#define LVCO_PIN	(1 << 3)

//Analogue input pins
#define B_SENSE_INPUT	2

#define FULL_BATT_VOLTAGE       ((float) 14.0)
#define CUTOFF_VOLTAGE          ((float) 10.9)
#define VCC_5V_SUPPLY           ((float) 5.15)
#define LOW_BATT_PERCENTAGE     ((float) 0.25)

//Converts the above levels to ADC values - [DONT EDIT]
//#define LOW_BATT_LEVEL	0xC4
#define LOW_BATT_VOLTAGE        ( (FULL_BATT_VOLTAGE-CUTOFF_VOLTAGE)*LOW_BATT_PERCENTAGE + CUTOFF_VOLTAGE )
#define LOW_BATT_LEVEL          ( (uint8_t) ( (LOW_BATT_VOLTAGE/(float)3) / (( VCC_5V_SUPPLY /(float)255) ) ))
//#define CUTOUT_LEVEL	0xB4
#define CUTOUT_LEVEL            ( (uint8_t) ( (CUTOFF_VOLTAGE/(float)3)/( VCC_5V_SUPPLY / (float)255) ) )

//State Machine States
#define STATE_ON 0
#define STATE_OFF 1

#define ADC_OVERSAMPLES 8

#define POLL_INTERVAL_MS 10 

//Global Variable
char state = STATE_ON;

//Function definitions
void init_hardware();
unsigned char read_ADC(char);

void main(void) {
    unsigned int adc_average;
    unsigned char adc_result, i;

    init_hardware();

    __delay_ms(500);

    while (1) {

        //Read the ADC and oversamples to improve accuracy
        adc_average = 0;
        for (i = 0; i < ADC_OVERSAMPLES; i++)
            adc_average += read_ADC(B_SENSE_INPUT);

        //Averages the read ADC samples
        adc_result = adc_average / ADC_OVERSAMPLES;

        //Processes the ADC value and switches outputs accordingly
        switch (state) {
            case STATE_ON:
                if (adc_result < CUTOUT_LEVEL) {
                    PORTC &= ~LEDG_PIN;
                    PORTC |= LEDR_PIN;
                    PORTC &= ~LVCO_PIN;
                    state = STATE_OFF;
                } else if (adc_result < LOW_BATT_LEVEL) {
                    PORTC |= (LEDR_PIN | LEDG_PIN | LVCO_PIN);
                } else {
                    PORTC |= ( LEDG_PIN | LVCO_PIN );
                    PORTC &= ~LEDR_PIN;
                }
                break;

            case STATE_OFF:
                if (LOW_BATT_LEVEL < adc_result) {
                    PORTC &= ~LEDR_PIN;
                    PORTC |= LEDG_PIN;
                    PORTC |= LVCO_PIN;
                    state = STATE_ON;
                }
                break;
        }

        //Waits a set time before reading the ADC again
        __delay_ms(POLL_INTERVAL_MS);

    }
}

void init_hardware(void) {

    //Allows the RC5 pin to be used as a GPIO pin
    OPTION = 0b11000000;

    //set all output ports to zero
    TRISC = ~(LVCO_PIN | LEDG_PIN | LEDR_PIN);

    //Turn on green LED
    PORTC &= ~(LEDG_PIN | LVCO_PIN);
    PORTC |= LEDR_PIN;

}

unsigned char read_ADC(char pin) {

    //Set up all AN pins as ADC inputs
    //Use Fosc/16 as clock for low power
    //Select correct input based on value passed in
    //Turn on ADC
    switch (pin) {
        case 0:
            ADCON0 = 0b11000001;
            break;
        case 1:
            ADCON0 = 0b11000101;
            break;
        case 2:
            ADCON0 = 0b11001001;
            break;
    }


    //Start the conversion
    ADCON0 |= 0x2;

    //Wait for conversion to finish
    while (ADCON0 & 0b00000010);

    //Turn off ADC to save power
    ADCON0 = 0b11000000;

    return ADRES;

}

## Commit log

2012-10-23 First Upload
    This is the hardware and software designs used for the 2012 battery box
    deployment at the hydro site.
    [battery_box.brd, battery_box.sch]
2012-11-14 Add license information
    [battery_box.brd, battery_box.sch]
2012-12-05 Added Connectors to Schematic
    Adds the DC Jacks and USB connectors and LEDs to the schematic for
    mounting on PCB. Added comments to schematic and changed .gitignore
    [battery_box.brd, battery_box.sch]
2013-01-11 Added cooments to fix problems identified
    Problems identified during 2013 Jan trip have added as comments.
    [battery_box.brd, battery_box.sch]
2013-02-27 Added the Connector Test PCB
    [battery_box.brd, battery_box.sch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]
2013-02-27 Version 0.1 of PIC16F1824 code
    Just turns some LEDs on and off at the moment.
2013-03-20 Electronics added.
    Should be first fully working prototype of 2013 unit. See README for
    changes from 2012 version.
    [battery_box.brd, battery_box.sch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]
2013-03-20 Added comments to Schematic
    [battery_box.sch]
2013-03-21 Changed location op a mp power supply
    [battery_box.brd, battery_box.sch]
2013-03-30 Added Latest Gerbers
    [battery_box.GBL, battery_box.GBO, battery_box.GBP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]
2013-03-30 Possible fix for ADC reading issues.
    [main.c]
2013-04-09 Fixed ADC Read Function
    Mistake in combine low and high bits. Was ANDing two together when
    should OR. ANDing will clear all bits.
    [main.c]
2013-04-13 ADC Works. Added I_SENSE code
    - Added current sense code as well as voltage measurement
2013-04-20 Code for writing to eeprom *untested*
    Added a line to set up ADC in bank C for I_Sense
    Still need to implement interrupts
2013-04-20 Added interrupt-on-change functionality for POW. *untested*
    Puts chip to sleep. Still untested.
2013-04-26 First PCB Layout
    [battery_box.brd, battery_box.sch]
2013-04-27 EEPROM code fully tested and working
    Contains some minor fixes
    [main.c]
2013-05-06 EEPROM code modified to work with PCB (in progress)
    Still in the process of testing
2013-05-10 Code modified to only cut off and turn back on
    All new features disabled.
2013-05-17 Updated the DC Jack and Battery Connector
    Fixed problems with footprints
    [battery_box.brd, battery_box.sch]
2013-05-17 Changed Current Sense Resistor Values
    [battery_box.brd, battery_box.sch]
2013-06-02 Fixed addressing of EEPROM
    [main.c]
2013-06-02 Fixed LED Pin Macros
    [main.c]
2013-06-02 Fixed Interrupt Code
    IOCAP |= 1 << 5; line was wrong, was previously setting up interrupt on
    in 4
    [main.c]
2013-06-04 Cleaned up and many code fixes
    Code fixes include:
    -Preset voltage levels for cutout was calculated for 8-bit ADC. Now
    correct for 10-bit ADC
    -Some Initilisation fixes
    - State machine ensures output pins are correct on each iteration
    [main.c]
2013-06-20 Working code
    Might be some bugs if battery voltage is between charging voltage and LV
    disconnect voltage. More testing is needed.
    [main.c]
2013-06-21 Light now no longer flickers when on
    It still flickers when voltage is low, but above cut off. This isn't a problem if we don't turn on red and green LED at the same time.
    Another problem: Light doesn't turn on when voltage is above cut off voltage, but below the charging voltage.
    [main.c]
2013-06-22 Attempted to make changes as discussed
    Changes left in complete routing.
    Sorted out the labels and added in diodes across the terminals and
    MOSFET, the Vreg with its caps and another decoupling cap for the PIC.
    See email for questions.
    [battery_box2.brd, battery_box2.sch]
2013-06-22 Cleaned up and routed PCB and Schematic files
    [battery_box2.brd, battery_box2.sch]
2013-06-23 Added new components with correct footprints
    [battery_box.brd, battery_box.sch, battery_box2.brd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]
2013-06-24 Re-routed PCB
    [battery_box2.brd, battery_box2.sch]
2013-06-25 Separated new and old PCB versions. Added Gerbers
    [battery_box.GBL, battery_box.GBO, battery_box.GBP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]
2013-06-30 added pdf of schematic
    [battery_box2.brd, battery_box2.sch]
2013-06-30 Board PDF
2013-07-01 updated C3 footprint and component values/cost
    [Battery box component list 2013 v2.xlsx, battery_box2.brd, battery_box2.sch]
2013-07-07 Most recent Gerbers
    Most recent footprints and testpoints added.
    [Battery box component list 2013 v2.xlsx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]
2013-09-01 Current sense now working
2013-09-05 Feature complete code (first release)
    *Requires more testing*
    Features:
    - LVDC
    - Low charge indication
    - Charging indication (box needs to be powered on for this to work)
    - Charging complete indication
    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
2013-09-07 Feature complete code (release 2)
    Contains minor bug fixes:
    - Charged indication flickers less (increased current threshold)
    - Tweaked the over current protection. Limit is now 800mA.
    [main.c]
2013-09-21 Feature complete code (release 3)
    Reduced the charging voltage to 12.3V
2013-11-06 Added Battery Box V3
    [battery_box3.GBL, battery_box3.GBO, battery_box3.GBP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]
2013-11-11 Battery box faceplate pdf added

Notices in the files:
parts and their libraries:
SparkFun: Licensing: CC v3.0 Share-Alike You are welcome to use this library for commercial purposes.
